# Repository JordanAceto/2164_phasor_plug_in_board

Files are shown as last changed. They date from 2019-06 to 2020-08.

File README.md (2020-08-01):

# NOTE: development of all VCF plug-in boards has been moved here https://github.com/JordanAceto/VCF_plug_in_boards
### This repo will no longer be updated. Follow the above link for the most current files.

# 2164 Phasor Plug-In Board

Small 6 stage SSM2164 based phase shifter PCB, designed to plug into a larger motherboard.

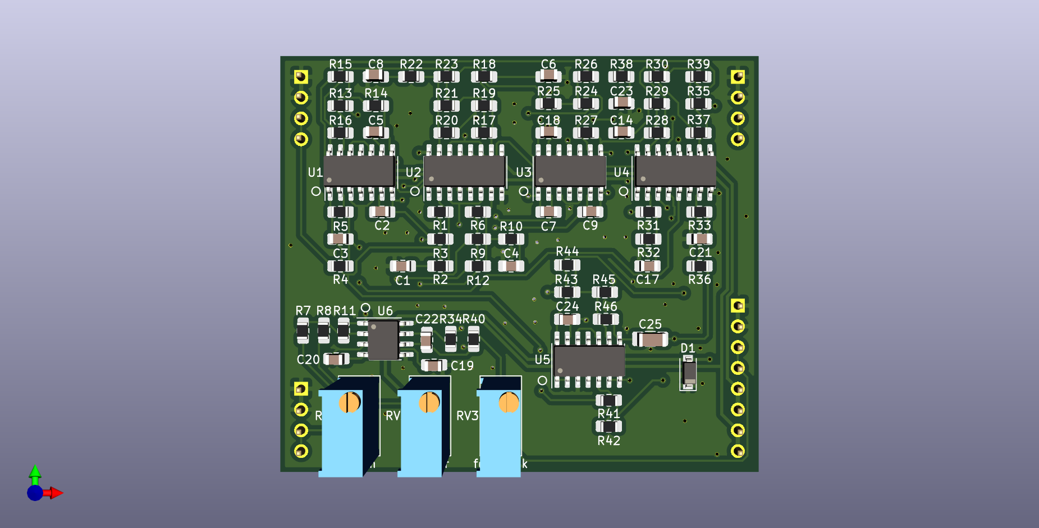
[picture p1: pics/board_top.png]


## Details

Six stage phase shifter implemented with SSM2164/V2164/SSI2164 quad VCAs. This PCB includes the audio path and CV inputs for frequency and feedback, but does not include any modulation sources.

The intended use for this board is to plug in to a larger motherboard which contains slots for two of these plug-in boards, as well as modulation sources, panel controls, and input/output routing. This motherboard could accept different filter boards sharing this footprint and header layout, for realizing stereo effects of various flavors.

## Inputs

-Audio in: dry audio input to be phase shifted.

-Frequency CV in: 0 volts to +2.048 volts, higher voltage = higher sweep.

-Feedback CV in: 0 volts to +2.048 volts, higher voltage = more feedback.

## Outputs

-Audio out: phase shifted audio output.

## Power Supply Requirements

A bipolar 12 volt power supply is needed. This will typically come from the motherboard.

## Calibration

-RV1 (depth trim): trims the depth of incoming frequency CV signals. Turn CW for greater depth and CCW for less depth. Adjust to taste.

-RV2 (center trim): trims the center frequency of the phase shifter. Turn CW for higher center frequency and CCW for lower center frequency. Adjust to taste.

-RV3 (feedback trim): trims the maximum amount of feedback. Turn CW for more maximum feedback and CCW for less maximum feedback. Exercise caution when adjusting this, as extreme settings can result in loud oscillations which could damage your ears or speakers if you are monitoring the sound with a loud amplifier. If you set this trimmer to be right on the edge of oscillation when about +2 volts is applied to the feedback CV input then make sure to sweep the frequency through its entire range, as a setting that doesn't squeal at certain frequency settings may squeal at other settings.

## Parts Ordering
The BOM has a link to a Mouser project with the majority of the parts needed to build the board, with the exception of the 2164 VCA chips. There is a link to the SmallBear Electronics parts page for these.

After the PCB is evaluated, the BOM will have a link to OSHPark, where you can order boards.

Zipped gerber files will be located in kicad_docs.

## License
CC by 4.0

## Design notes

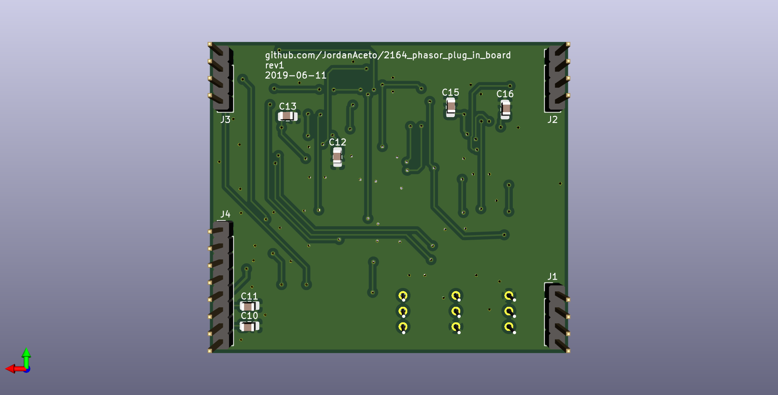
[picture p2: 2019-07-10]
pics/board_bottom.png

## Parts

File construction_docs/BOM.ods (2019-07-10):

Reference | Quantity | Value | Footprint | Unit Price | Total Price | Product Page
Mouser Parts
C1 C21 C4 C6 C8 C14 C23 C17 | 8 | 560pF | 0805 | $0.18 | $1.44 | https://www.mouser.com/ProductDetail/Yageo/CC0805JRNPO9BN511
C19 C20 C15 C16 C12 C13 C10 C11 | 8 | 100nF | 0805 | $0.10 | $0.80 | https://www.mouser.com/ProductDetail/KEMET/C0805C104M5RACTU
C2 C5 C7 C9 C18 C24 | 6 | 220pF | 0805 | $0.27 | $1.62 | https://www.mouser.com/ProductDetail/Yageo/CC0805FRNPO9BN221
C22 | 1 | 100pF | 0805 | $0.13 | $0.13 | https://www.mouser.com/ProductDetail/Yageo/CC0805JRNPO9BN101
C25 | 1 | 220nF | 1206 | $0.80 | $0.80 | https://www.mouser.com/ProductDetail/Cornell-Dubilier-CDE/FCA1206C224M-H1
C3 | 1 | 470pF | 0805 | $0.14 | $0.14 | https://www.mouser.com/ProductDetail/Yageo/CC0805JRNPO9BN471
D1 | 1 | BAT48ZFILM | SOD-123 | $0.45 | $0.45 | https://www.mouser.com/ProductDetail/STMicroelectronics/BAT48ZFILM
J1 J2 J3 J4 | 1 | breakaway headers | PinHeader_2.54mm | $2.78 | $2.78 | https://www.mouser.com/ProductDetail/TE-Connectivity/4-103185-0
R14 R13 R25 R24 R44 R43 | 6 | 10k | 0805 | $0.10 | $0.60 | https://www.mouser.com/ProductDetail/Bourns/CR0805-FX-1002ELF
R16 R15 R27 R26 R46 R45 | 6 | 20k | 0805 | $0.10 | $0.60 | https://www.mouser.com/ProductDetail/Bourns/CR0805-FX-2002ELF
R2 R33 R10 R18 R22 R29 R38 R32 | 8 | 510 | 0805 | $0.10 | $0.80 | https://www.mouser.com/ProductDetail/Bourns/CR0805-FX-5100ELF
R3 R1 R9 R12 R19 R17 R21 R23 R30 R28 R37 R39 R41 R5 R4 R36 | 16 | 30k | 0805 | $0.10 | $1.60 | https://www.mouser.com/ProductDetail/Bourns/CR0805-FX-3002ELF
R31 | 1 | 270k | 0805 | $0.10 | $0.10 | https://www.mouser.com/ProductDetail/Bourns/CR0805-FX-2703ELF
R34 | 1 | 4k7 | 0805 | $0.10 | $0.10 | https://www.mouser.com/ProductDetail/Bourns/CR0805-FX-4701ELF
R40 | 1 | 51k | 0805 | $0.10 | $0.10 | https://www.mouser.com/ProductDetail/Bourns/CR0805-FX-5102ELF
R42 | 1 | 12k | 0805 | $0.10 | $0.10 | https://www.mouser.com/ProductDetail/Bourns/CR0805-FX-1202ELF
R6 R20 R35 | 3 | 15k | 0805 | $0.10 | $0.30 | https://www.mouser.com/ProductDetail/Bourns/CR0805-FX-1502ELF
R7 R11 | 2 | 100k | 0805 | $0.10 | $0.20 | https://www.mouser.com/ProductDetail/Bourns/CR0805-FX-1003ELF
R8 | 1 | 330k | 0805 | $0.10 | $0.10 | https://www.mouser.com/ProductDetail/Bourns/CR0805-FX-3303ELF
RV1 | 1 | 10k | Bourns_3269W | $1.54 | $1.54 | https://www.mouser.com/ProductDetail/BI-Technologies-TT-Electronics/67WR10KLF
RV2 RV3 | 2 | 100k | Bourns_3269W | $1.57 | $3.14 | https://www.mouser.com/ProductDetail/BI-Technologies-TT-Electronics/67WR100KLF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
U1 U3 U5 | 3 | TL074 | SOIC-14 | $0.60 | $1.80 | https://www.mouser.com/ProductDetail/STMicroelectronics/TL074IYDT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
U6 | 1 | TL072 | SOIC-8 | $0.59 | $0.59 | https://www.mouser.com/ProductDetail/Texas-Instruments/TL072CDR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
 |  |  | Mouser total: |  | $19.83
 |  |  | Link to Mouser project: |  |  | https://www.mouser.com/ProjectManager/ProjectDetail.aspx?AccessID=6604f1b034
Non-Mouser Parts
U2 U4 | 2 | SSM2164 | SOIC-16 | $3.95 | $7.90 | http://smallbear-electronics.mybigcommerce.com/ic-v2164m/

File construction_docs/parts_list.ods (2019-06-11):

Reference | Quantity | Value | Footprint
C1 C21 C4 C6 C8 C14 C23 C17 | 8 | 560pF | 0805
C19 C20 C15 C16 C12 C13 C10 C11 | 8 | 100nF | 0805
C2 C5 C7 C9 C18 C24 | 6 | 220pF | 0805
C22 | 1 | 100pF | 0805
C25 | 1 | 220nF | 1206
C3 | 1 | 470pF | 0805
D1 | 1 | BAT48ZFILM | SOD-123
J1 J2 J3 J4 | 1 | breakaway headers | PinHeader_2.54mm
R14 R13 R25 R24 R44 R43 | 6 | 10k | 0805
R16 R15 R27 R26 R46 R45 | 6 | 20k | 0805
R2 R33 R10 R18 R22 R29 R38 R32 | 8 | 510 | 0805
R3 R1 R9 R12 R19 R17 R21 R23 R30 R28 R37 R39 R41 R5 R4 R36 | 16 | 30k | 0805
R31 | 1 | 270k | 0805
R34 | 1 | 4k7 | 0805
R40 | 1 | 51k | 0805
R42 | 1 | 12k | 0805
R6 R20 R35 | 3 | 15k | 0805
R7 R11 | 2 | 100k | 0805
R8 | 1 | 330k | 0805
RV1 | 1 | 10k | Bourns_3269W
RV2 RV3 | 2 | 100k | Bourns_3269W
U1 U3 U5 | 3 | TL074 | SOIC-14
U6 | 1 | TL072 | SOIC-8
U2 U4 | 2 | SSM2164 | SOIC-16

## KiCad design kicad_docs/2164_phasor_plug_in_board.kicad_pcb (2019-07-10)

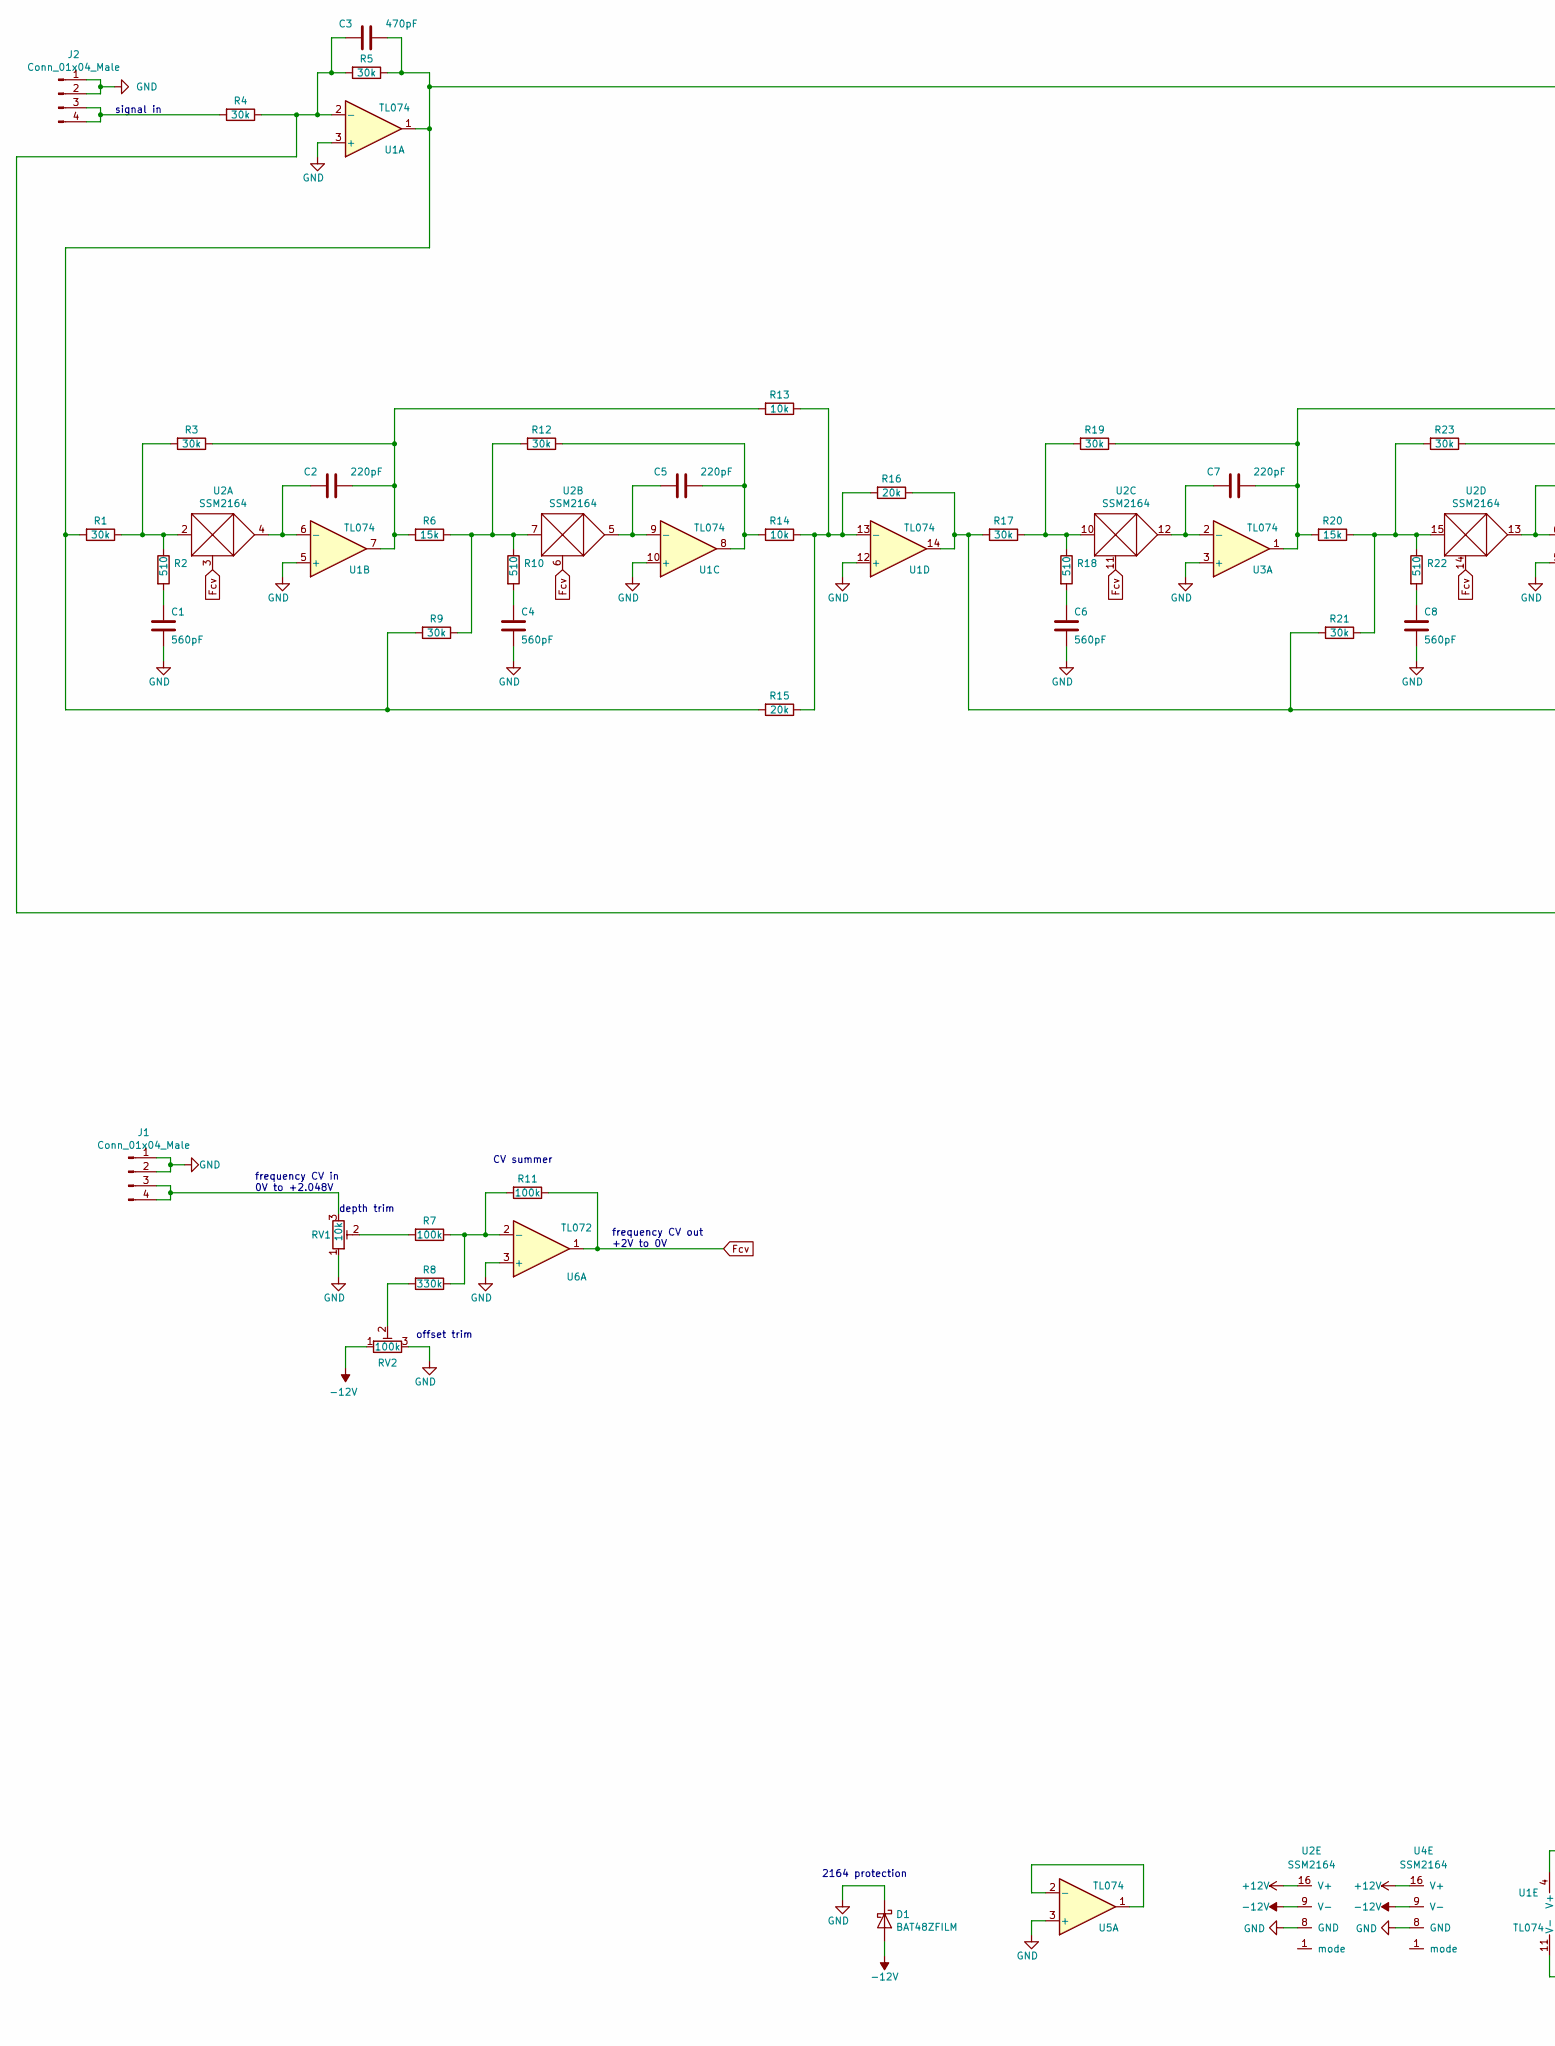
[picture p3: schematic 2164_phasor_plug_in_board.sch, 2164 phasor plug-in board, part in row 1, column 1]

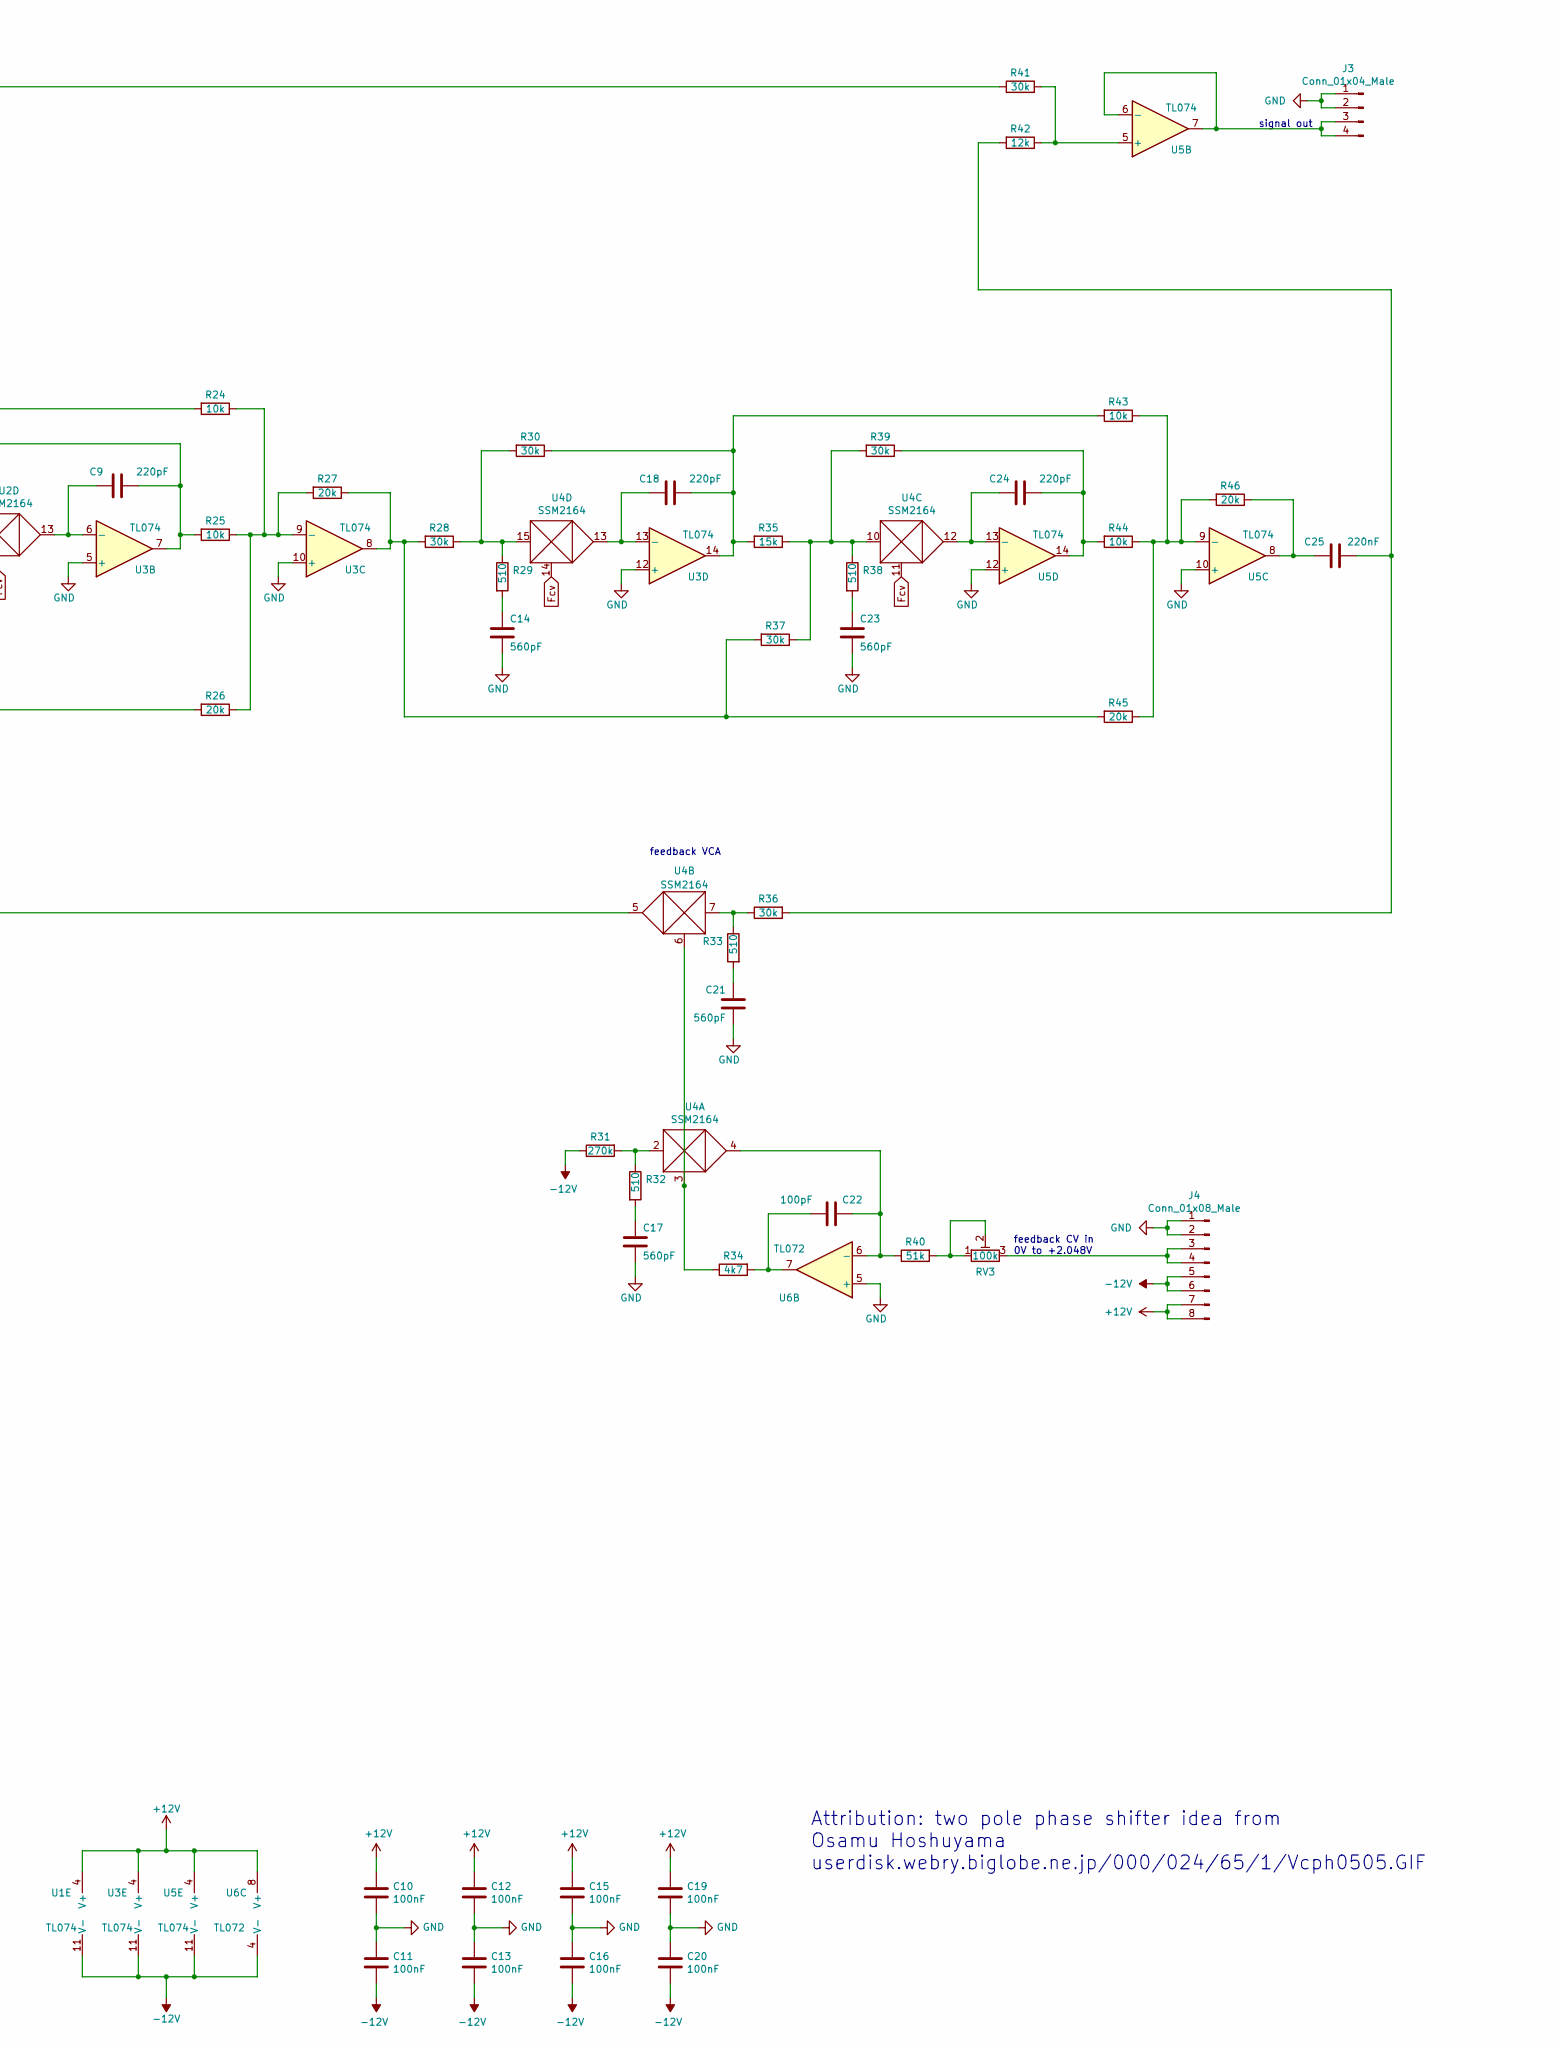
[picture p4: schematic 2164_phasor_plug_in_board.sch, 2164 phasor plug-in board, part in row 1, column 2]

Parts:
C1, C4, C6, C8, C14, C17, C21, C23: 560pF; C_0805_2012Metric_Pad1.15x1.40mm_HandSolder
C2, C5, C7, C9, C18, C24: 220pF; C_0805_2012Metric_Pad1.15x1.40mm_HandSolder
C3: 470pF; C_0805_2012Metric_Pad1.15x1.40mm_HandSolder
C10, C11, C12, C13, C15, C16, C19, C20: 100nF; C_0805_2012Metric_Pad1.15x1.40mm_HandSolder
C22: 100pF; C_0805_2012Metric_Pad1.15x1.40mm_HandSolder
C25: 220nF; C_1206_3216Metric_Pad1.42x1.75mm_HandSolder
D1: BAT48ZFILM; D_SOD-123
J1, J2, J3: Conn_01x04_Male; PinHeader_1x04_P2.54mm_Vertical
J4: Conn_01x08_Male; PinHeader_1x08_P2.54mm_Vertical
R1, R3, R4, R5, R9, R12, R17, R19, R21, R23, R28, R30, R36, R37, R39, R41: 30k; R_0805_2012Metric_Pad1.15x1.40mm_HandSolder
R2, R10, R18, R22, R29, R32, R33, R38: 510; R_0805_2012Metric_Pad1.15x1.40mm_HandSolder
R6, R20, R35: 15k; R_0805_2012Metric_Pad1.15x1.40mm_HandSolder
R7, R11: 100k; R_0805_2012Metric_Pad1.15x1.40mm_HandSolder
R8: 330k; R_0805_2012Metric_Pad1.15x1.40mm_HandSolder
R13, R14, R24, R25, R43, R44: 10k; R_0805_2012Metric_Pad1.15x1.40mm_HandSolder
R15, R16, R26, R27, R45, R46: 20k; R_0805_2012Metric_Pad1.15x1.40mm_HandSolder
R31: 270k; R_0805_2012Metric_Pad1.15x1.40mm_HandSolder
R34: 4k7; R_0805_2012Metric_Pad1.15x1.40mm_HandSolder
R40: 51k; R_0805_2012Metric_Pad1.15x1.40mm_HandSolder
R42: 12k; R_0805_2012Metric_Pad1.15x1.40mm_HandSolder
RV1: 10k; Potentiometer_Bourns_3296W_Vertical
RV2, RV3: 100k; Potentiometer_Bourns_3296W_Vertical
U1, U3, U5: TL074; SOIC-14_3.9x8.7mm_P1.27mm
U2, U4: SSM2164; SOIC-16_3.9x9.9mm_P1.27mm
U6: TL072; SOIC-8_3.9x4.9mm_P1.27mm

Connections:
+12V: C10.1, C12.1, C15.1, C19.1, J4.7, J4.8, U1.4 (V+), U2.16 (V+), U3.4 (V+), U4.16 (V+), U5.4 (V+), U6.8 (V+)
-12V: C11.2, C13.2, C16.2, C20.2, D1.2 (A), J4.5, J4.6, R31.1, RV2.1, U1.11 (V-), U2.9 (V-), U3.11 (V-), U4.9 (V-), U5.11 (V-), U6.4 (V-)
Fcv: R11.1, U2.3, U2.6, U2.11, U2.14, U4.11, U4.14, U6.1
GND: C1.2, C4.2, C6.2, C8.2, C10.2, C11.1, C12.2, C13.1, C14.2, C15.2, C16.1, C17.2, C19.2, C20.1, C21.2, C23.2, D1.1 (K), J1.1, J1.2, J2.1, J2.2, J3.1, J3.2, J4.1, J4.2, RV1.1, RV2.3, U1.3 (+), U1.5 (+), U1.10 (+), U1.12 (+), U2.8 (GND), U3.3 (+), U3.5 (+), U3.10 (+), U3.12 (+), U4.8 (GND), U5.3 (+), U5.10 (+), U5.12 (+), U6.3 (+), U6.5 (+)
unnamed: C1.1, R2.2
unnamed: C2.1, R3.1, R6.2, R13.2, U1.7
unnamed: C2.2, U1.6 (-), U2.4
unnamed: C3.1, R1.2, R5.1, R9.2, R15.2, R41.1, U1.1
unnamed: C3.2, R4.1, R5.2, U1.2 (-), U4.5
unnamed: C4.1, R10.2
unnamed: C5.1, R12.1, R14.2, U1.8
unnamed: C5.2, U1.9 (-), U2.5
unnamed: C6.1, R18.2
unnamed: C7.1, R19.1, R20.2, R24.2, U3.1
unnamed: C7.2, U2.12, U3.2 (-)
unnamed: C8.1, R22.2
unnamed: C9.1, R23.1, R25.2, U3.7
unnamed: C9.2, U2.13, U3.6 (-)
unnamed: C14.1, R29.2
unnamed: C17.1, R32.2
unnamed: C18.1, R30.1, R35.2, R43.2, U3.14
unnamed: C18.2, U3.13 (-), U4.13
unnamed: C21.1, R33.2
unnamed: C22.1, R34.2, U6.7
unnamed: C22.2, R40.1, U4.4, U6.6 (-)
unnamed: C23.1, R38.2
unnamed: C24.1, R39.1, R44.2, U5.14
unnamed: C24.2, U4.12, U5.13 (-)
unnamed: C25.1, R36.2, R42.2
unnamed: C25.2, R46.1, U5.8
unnamed: J1.3, J1.4, RV1.3
unnamed: J2.3, J2.4, R4.2
unnamed: J3.3, J3.4, U5.6 (-), U5.7
unnamed: J4.3, J4.4, RV3.3
unnamed: R1.1, R2.1, R3.2, U2.2
unnamed: R7.2, RV1.2
unnamed: R8.2, RV2.2
unnamed: R6.1, R9.1, R10.1, R12.2, U2.7
unnamed: R7.1, R8.1, R11.2, U6.2 (-)
unnamed: R13.1, R14.1, R15.1, R16.2, U1.13 (-)
unnamed: R16.1, R17.2, R21.2, R26.2, U1.14
unnamed: R17.1, R18.1, R19.2, U2.10
unnamed: R20.1, R21.1, R22.1, R23.2, U2.15
unnamed: R24.1, R25.1, R26.1, R27.2, U3.9 (-)
unnamed: R27.1, R28.2, R37.2, R45.2, U3.8
unnamed: R28.1, R29.1, R30.2, U4.15
unnamed: R31.2, R32.1, U4.2
unnamed: R33.1, R36.1, U4.7
unnamed: R34.1, U4.3, U4.6
unnamed: R35.1, R37.1, R38.1, R39.2, U4.10
unnamed: R40.2, RV3.1, RV3.2
unnamed: R41.2, R42.1, U5.5 (+)
unnamed: R43.1, R44.1, R45.1, R46.2, U5.9 (-)
unnamed: U5.1, U5.2 (-)

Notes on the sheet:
offset trim
depth trim
frequency CV in 0V to +2.048V
signal in
signal out
feedback CV in 0V to +2.048V
frequency CV out +2V to 0V
Attribution: two pole phase shifter idea from Osamu Hoshuyama userdisk.webry.biglobe.ne.jp/000/024/65/1/Vcph0505.GIF
2164 protection
feedback VCA
CV summer

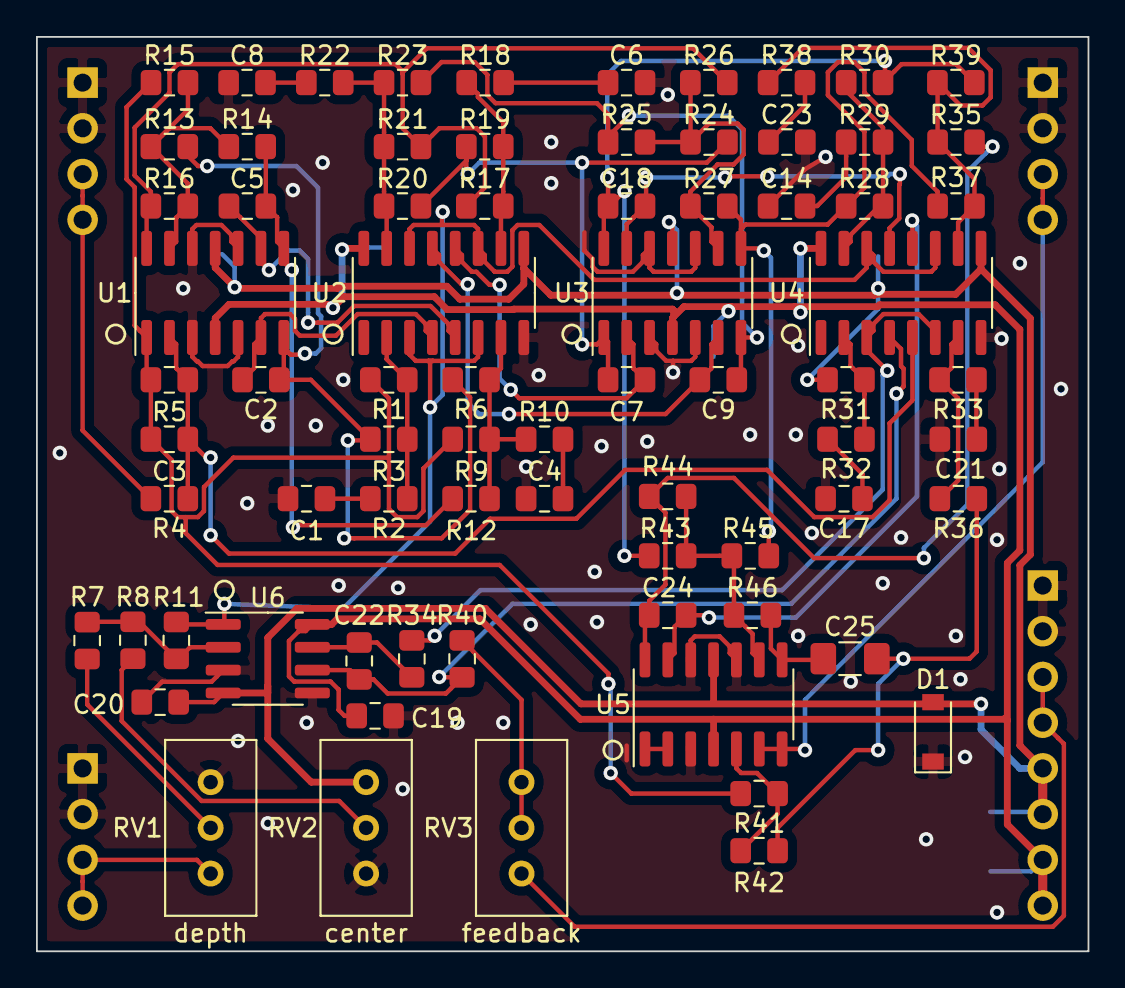
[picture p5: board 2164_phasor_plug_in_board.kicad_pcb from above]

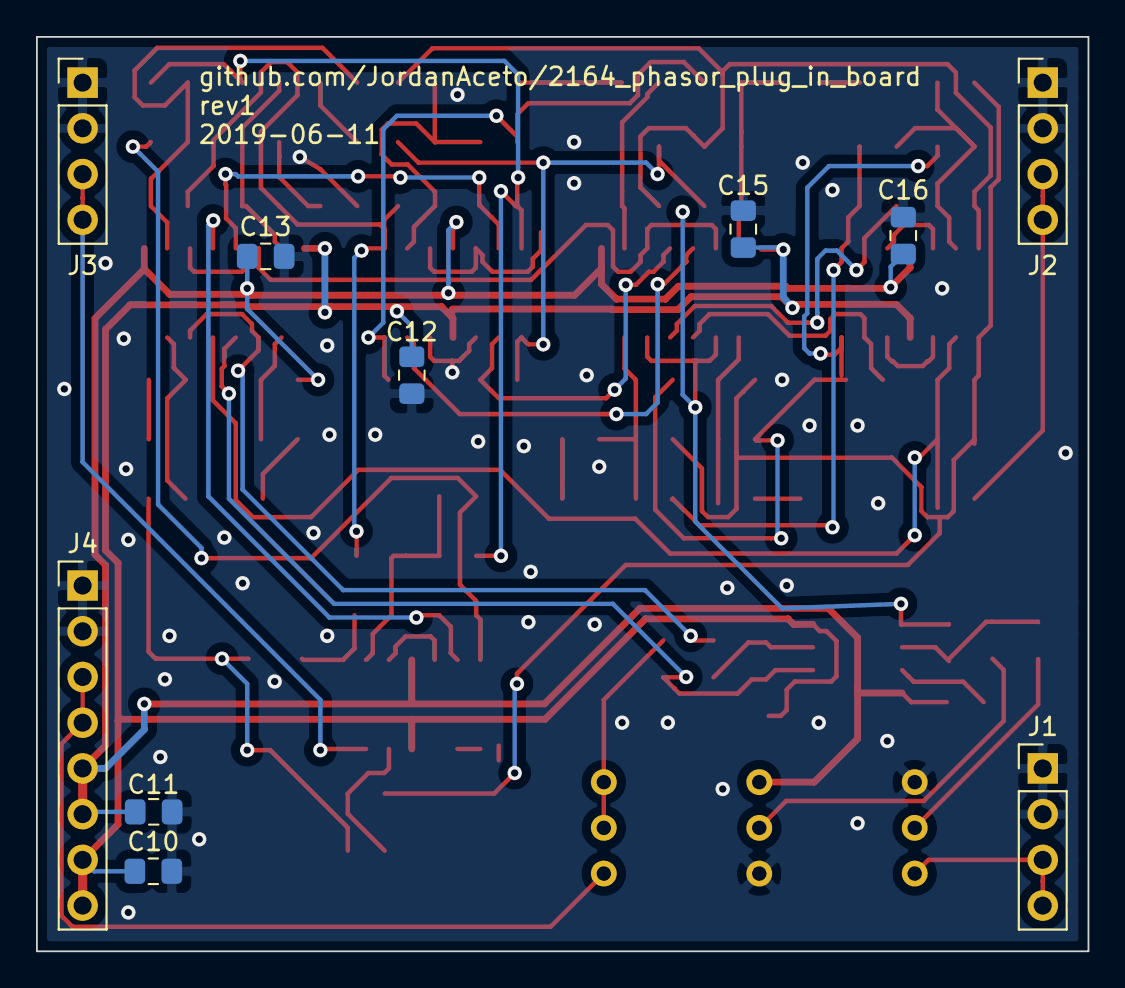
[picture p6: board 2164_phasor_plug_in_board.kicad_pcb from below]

Board: 2 copper layers, 58.4 x 50.8 mm, 85 parts (10 on the bottom side), 54 nets.

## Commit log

2019-06-11 add github url to board, add pic of board bottom
    [2164_phasor_plug_in_board.kicad_pcb]
2019-06-11 add link to mouser project in BOM, update README
    [BOM.ods]
2019-06-11 add parts list to construction docs
    [parts_list.ods]
2019-07-10 change trimmers to cheaper TH type
    [2164_phasor_plug_in_board.kicad_pcb, 2164_phasor_plug_in_board.sch]
2019-07-10 update board pics to reflect TH trimmers
2019-07-10 update BOM with cheaper TH trimmers
    [BOM.ods]

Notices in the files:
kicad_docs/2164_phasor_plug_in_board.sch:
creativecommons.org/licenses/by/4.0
